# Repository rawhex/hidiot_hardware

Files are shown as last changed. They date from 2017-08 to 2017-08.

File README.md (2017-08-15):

# HIDIOT Hardware

This is the repo for the HIDIOT hardware. It contains the following:

* HIDIOT Schematics and Board definitions for Eagle CAD
* HIDIOT Schematic in PNG format
* This README

The HIDIOT uses the Arduino IDE in either Trinket or Digispark compatible configuration with the appropriate software. Digispark is the preferred framework. Please see [here](https://github.com/digistump/DigistumpArduino) for source code, including the V-USB library used for communication.



## Creating your own HIDIOT

There's a couple of gotchas that you should be aware of depending on what you're using it for and what modifications you want to make. It's probably best to drop an email to pcb@hidiot.com where we can help you make sure your design both works properly and respects our trademarks.

If you're looking to make one for your own personal use, please do fill your boots (but let us know above so we can help).

If you want to create HIDIOTs for an event or a group, we're more than happy for you to do so providing you make your board substantially unique in some way, and you obviously can't use the terms HIDIOT or Raw Hex in your designor name without express written permission. If you want to use these terms, just write to us, and we'll have a chat.

If you're looking to create HIDIOTs commercially, then please make sure that your HIDIOT has a fundamental difference, and of course you can't use terms like HIDIOT or Raw Hex anywhere in your product's design or implementation. You'll also need to be careful about how you use our documentation, which is licenced separately. Talking to us up front will help avoid possible problems later on and we're happy to advise on how to do this correctly.

## Partnering with us

We do provide custom board designs and can provide licences and support for various forms of commercial use. Please contact us at support at rawhex dot com. We'd love to work with you!

## Thanks

There are several people we'd like to thank. All of these people helped, possibly without knowing it. Without these people the HIDIOT would not be possible. If you're not on the list and think you should be, drop us a line.

* Sammy Verity
* Dominic Spill
* Erik Kettenburg
* Saumil Shah
* Dhillon 'L33tdawg' Kannabhiran
* Pete Herzog
* Joe Fitzpatrick
* Don A. Bailey
* cpldcpu
* Jenna Fox
* ihsan Kehribar
* Objective Development Software GmBH
* All of our Kickstarter backers

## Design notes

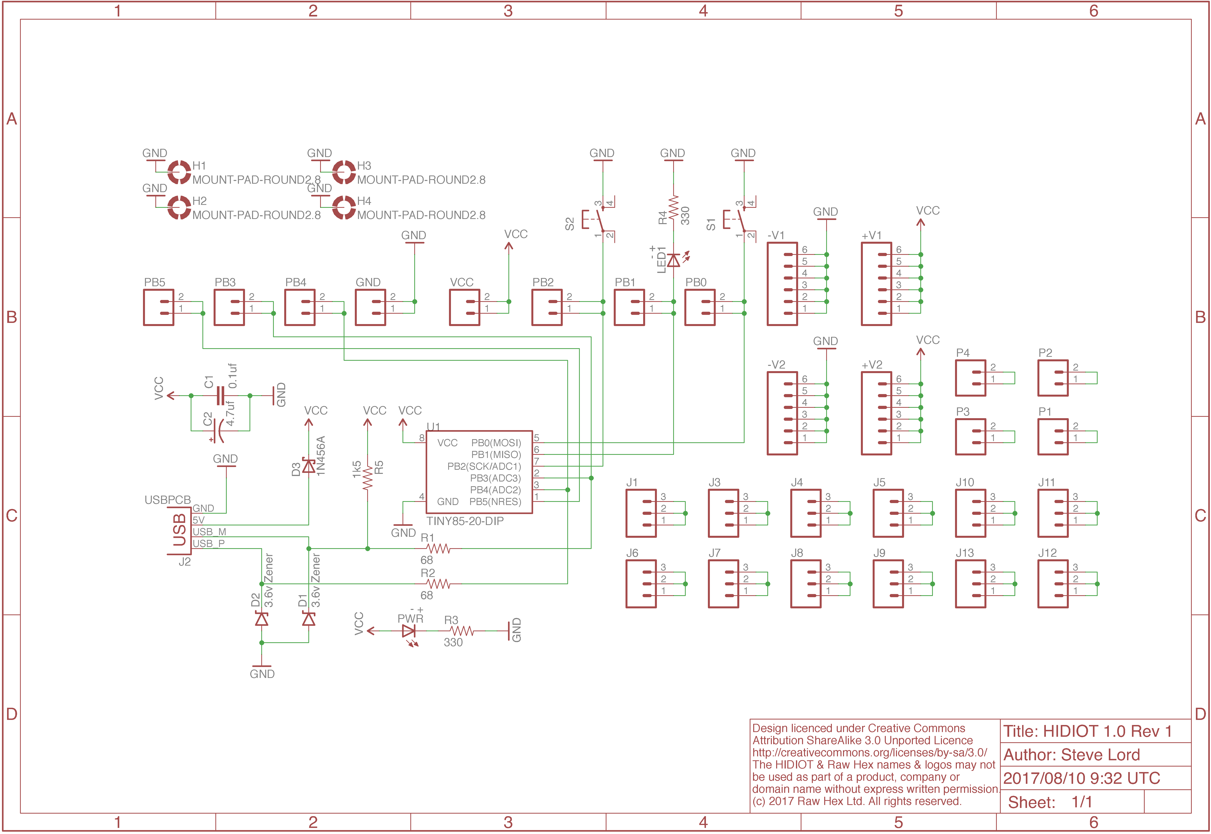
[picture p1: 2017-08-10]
hidiot_1.0_final.png

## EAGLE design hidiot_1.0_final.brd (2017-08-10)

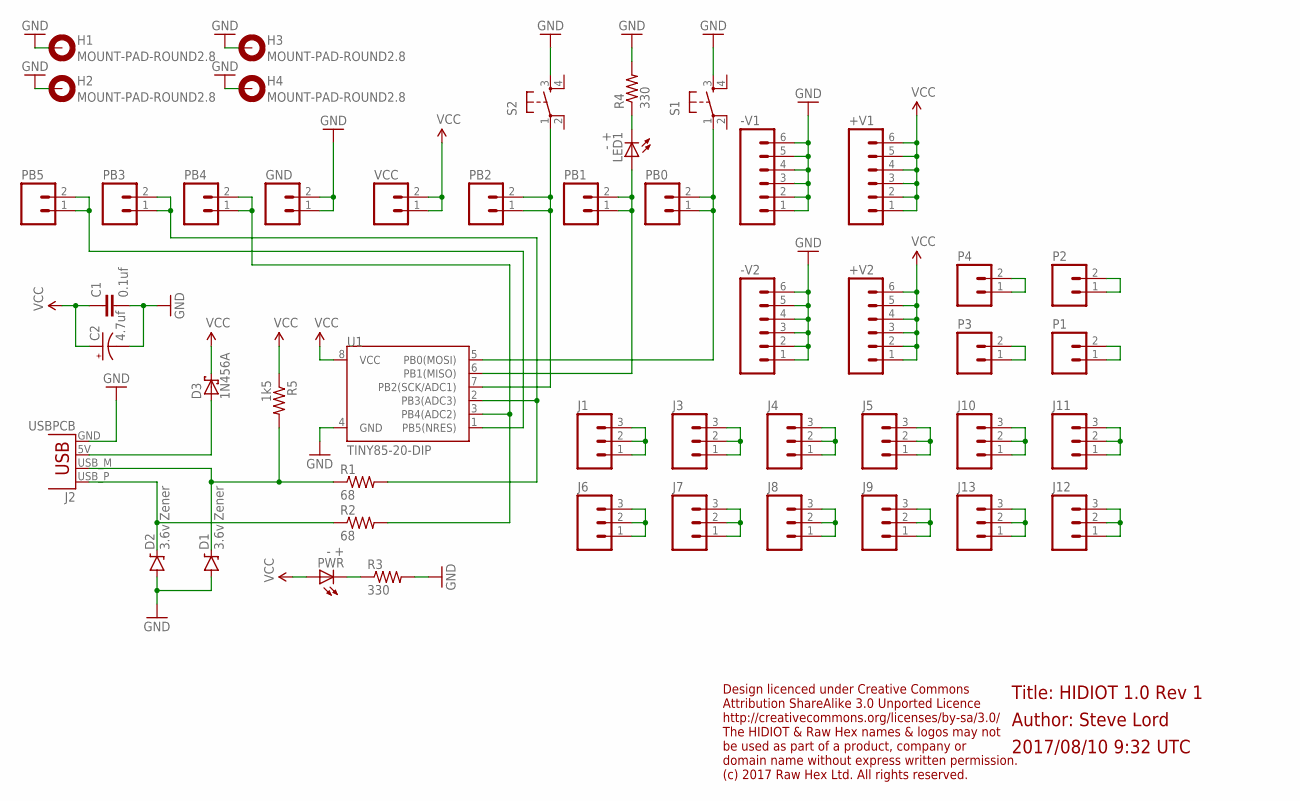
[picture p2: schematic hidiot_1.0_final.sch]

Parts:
+V1, +V2: M06SILK_FEMALE_PTH; 1X06
-V1, -V2: M06SILK_FEMALE_PTH; 1X06
C1: 0.1uf; CAP-PTH-SMALL-KIT; MPN K104K15X7RF5TH5
C2: 4.7uf; CPOL-RADIAL-100UF-25V; MPN MCGPR50V475M5X11
D1, D2: 3.6v Zener; DIODE-ZENER; MPN 1N4729A
D3: 1N456A; DIODE_DO35-7; MPN 1N456A
GND: M02PTH; 1X02
H1, H2, H3, H4: MOUNT-PAD-ROUND2.8; 2,8-PAD
J1, J3, J4, J5, J6, J7, J8, J9, J10, J11, J12, J13: M03PTH; 1X03
J2: USBPCB; USB-A-PCB
LED1: - +; LED3MM; MPN HLMP-K150
P1, P2, P3, P4: M02PTH; 1X02
PB0, PB1, PB2, PB3, PB4, PB5: M02PTH; 1X02
PWR: - +; LED3MM; MPN HLMP-K150
R1, R2: 68; AXIAL-0.4; MPN MCF 0.25W 68R
R3, R4: 330; AXIAL-0.4; MPN MCF 0.25W 68R
R5: 1k5; AXIAL-0.4; MPN MCF 1W 1K5
S1, S2: TAC_SWITCHPTH; TACTILE-PTH
U1: TINY85-20-DIP; DIP08; MPN ATTINY85-20PU
VCC: M02PTH; 1X02

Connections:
GND: -V1.1, -V1.2, -V1.3, -V1.4, -V1.5, -V1.6, -V2.1, -V2.2, -V2.3, -V2.4, -V2.5, -V2.6, C1.2, C2.2 (-), D1.P$2 (A), D2.P$2 (A), GND.1, GND.2, H1.B2,8, H2.B2,8, H3.B2,8, H4.B2,8, J2.GND, R3.P$2 (2), R4.P$2 (2), S1.3, S2.3, U1.4 (GND)
unnamed: PB5.1, PB5.2, U1.1 (PB5(NRES))
unnamed: LED1.K (C), R4.P$1 (1)
unnamed: PB2.1, PB2.2, S2.1, U1.7 (PB2(SCK/ADC1))
unnamed: PB3.1, PB3.2, R1.P$2 (2), U1.2 (PB3(ADC3))
unnamed: PB4.1, PB4.2, R2.P$2 (2), U1.3 (PB4(ADC2))
unnamed: PB0.1, PB0.2, S1.1, U1.5 (PB0(MOSI))
unnamed: D2.P$1 (C), J2.USB_P (D+), R2.P$1 (1)
unnamed: D1.P$1 (C), J2.USB_M (D-), R1.P$1 (1), R5.P$2 (2)
unnamed: D3.A (C), J2.5V (VBUS)
unnamed: LED1.A, PB1.1, PB1.2, U1.6 (PB1(MISO))
unnamed: PWR.K (C), R3.P$1 (1)
unnamed: J1.1, J1.2, J1.3
unnamed: J3.1, J3.2, J3.3
unnamed: J4.1, J4.2, J4.3
unnamed: J5.1, J5.2, J5.3
unnamed: J8.1, J8.2, J8.3
unnamed: J7.1, J7.2, J7.3
unnamed: J6.1, J6.2, J6.3
unnamed: J9.1, J9.2, J9.3
unnamed: J10.1, J10.2, J10.3
unnamed: J11.1, J11.2, J11.3
unnamed: J12.1, J12.2, J12.3
unnamed: J13.1, J13.2, J13.3
unnamed: P1.1, P1.2
unnamed: P2.1, P2.2
unnamed: P3.1, P3.2
unnamed: P4.1, P4.2
VCC: +V1.1, +V1.2, +V1.3, +V1.4, +V1.5, +V1.6, +V2.1, +V2.2, +V2.3, +V2.4, +V2.5, +V2.6, C1.1, C2.1 (+), D3.C (A), PWR.A, R5.P$1 (1), U1.8 (VCC), VCC.1, VCC.2

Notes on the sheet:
Author: Steve Lord
Title: HIDIOT 1.0 Rev 1
2017/08/10 9:32 UTC
Design licenced under Creative Commons Attribution ShareAlike 3.0 Unported Licence http://creativecommons.org/licenses/by-sa/3.0/ The HIDIOT & Raw Hex names & logos may not be used as part of a product, company or domain name without express written permission. (c) 2017 Raw Hex Ltd. All rights rese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

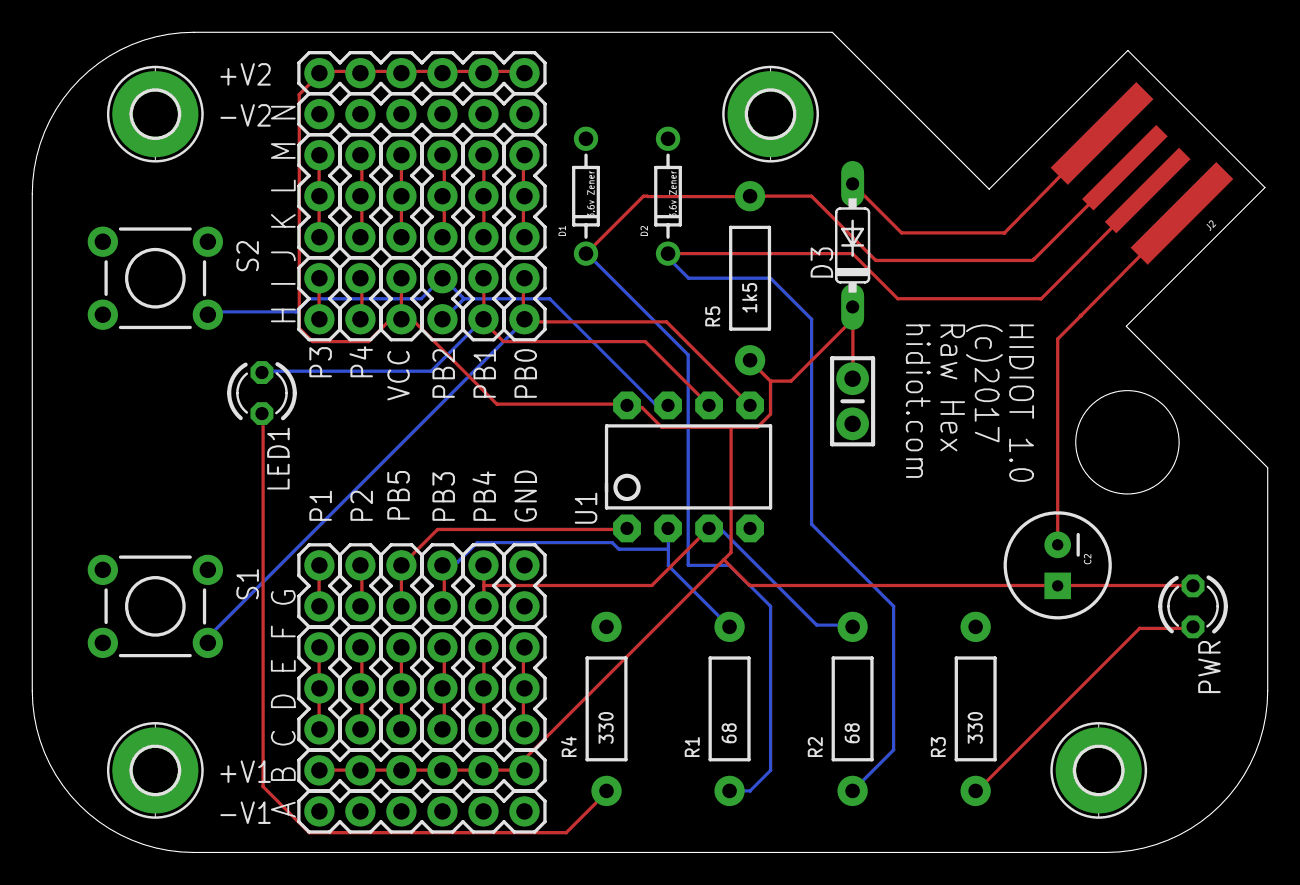
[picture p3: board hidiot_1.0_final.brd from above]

Board: 2 copper layers, 76.5 x 50.8 mm, 48 parts (0 on the bottom side), 29 nets.

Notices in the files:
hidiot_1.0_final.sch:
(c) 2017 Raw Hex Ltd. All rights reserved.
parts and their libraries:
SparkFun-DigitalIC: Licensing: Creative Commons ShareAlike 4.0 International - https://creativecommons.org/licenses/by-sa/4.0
